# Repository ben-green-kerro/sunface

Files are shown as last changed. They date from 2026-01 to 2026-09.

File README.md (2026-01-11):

# sunface
A big light for your face so you can wake up.

This project aims to provide a bright light to help stimulate wakefullness in the absence of natural light. Our bodies naturally wake when sunlight enters our eyes, even through closed eyelids. Through a WiFi connection, this light may be configured through Apple's HomeKit to smoothly turn on over the course of 30 minutes to reach full brightness at a specific time of desired waking.

White LEDs of a cool 6500k spectrum align with natural sunlight and is also similar in colour spectrum to LEDs used in lamps to treat seasonal affective disorder (SAD). Further to this, the lights brightness is flicker-free due to it the LEDs being powered by constant current driver ICs which is supposed to yield a marked improvement over pulse width modulation for eye-comfort.

A generic wall mount option is available, but the system may also be configured to be attached to a headboard by swapping out the 3D printed mounts at the ends of the light, although this will require some custom design work due to the differences in bed frames.

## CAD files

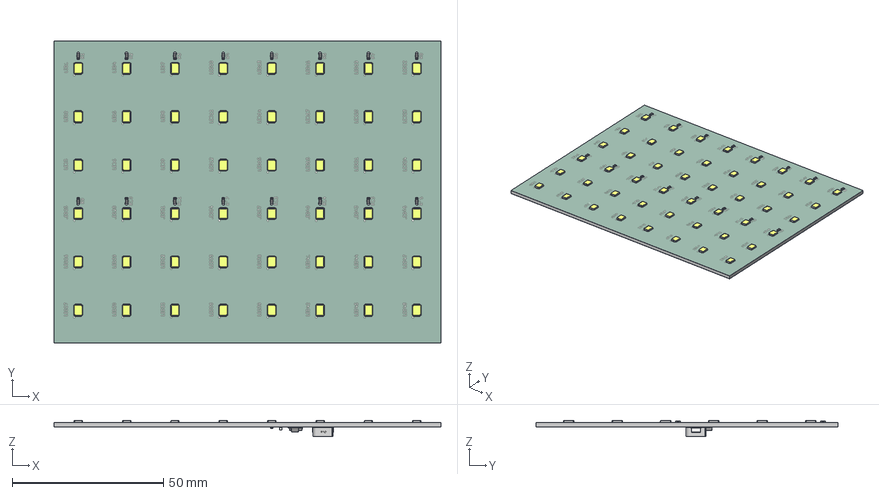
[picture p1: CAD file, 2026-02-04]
hardware/all_in_one/3D Files/sunface.step
128.0 x 100.0 x 5.43 mm
R_0603_1608Metric x 17
LED-SMD_L3.5-W2.8-RD_1.25T-2PWT x 48
C_0603_1608Metric
SOT-89-5_L4.5-W2.5-H1.5-LS4.1-P1.50
IND-SMD_L6.6-W7.1-H3.0
SMA_L4.3-W2.6-LS5.0-RD
sunface_copper
sunface_pad
sunface_via
sunface_silkscreen x 2
sunface_soldermask x 2
sunface_PCB

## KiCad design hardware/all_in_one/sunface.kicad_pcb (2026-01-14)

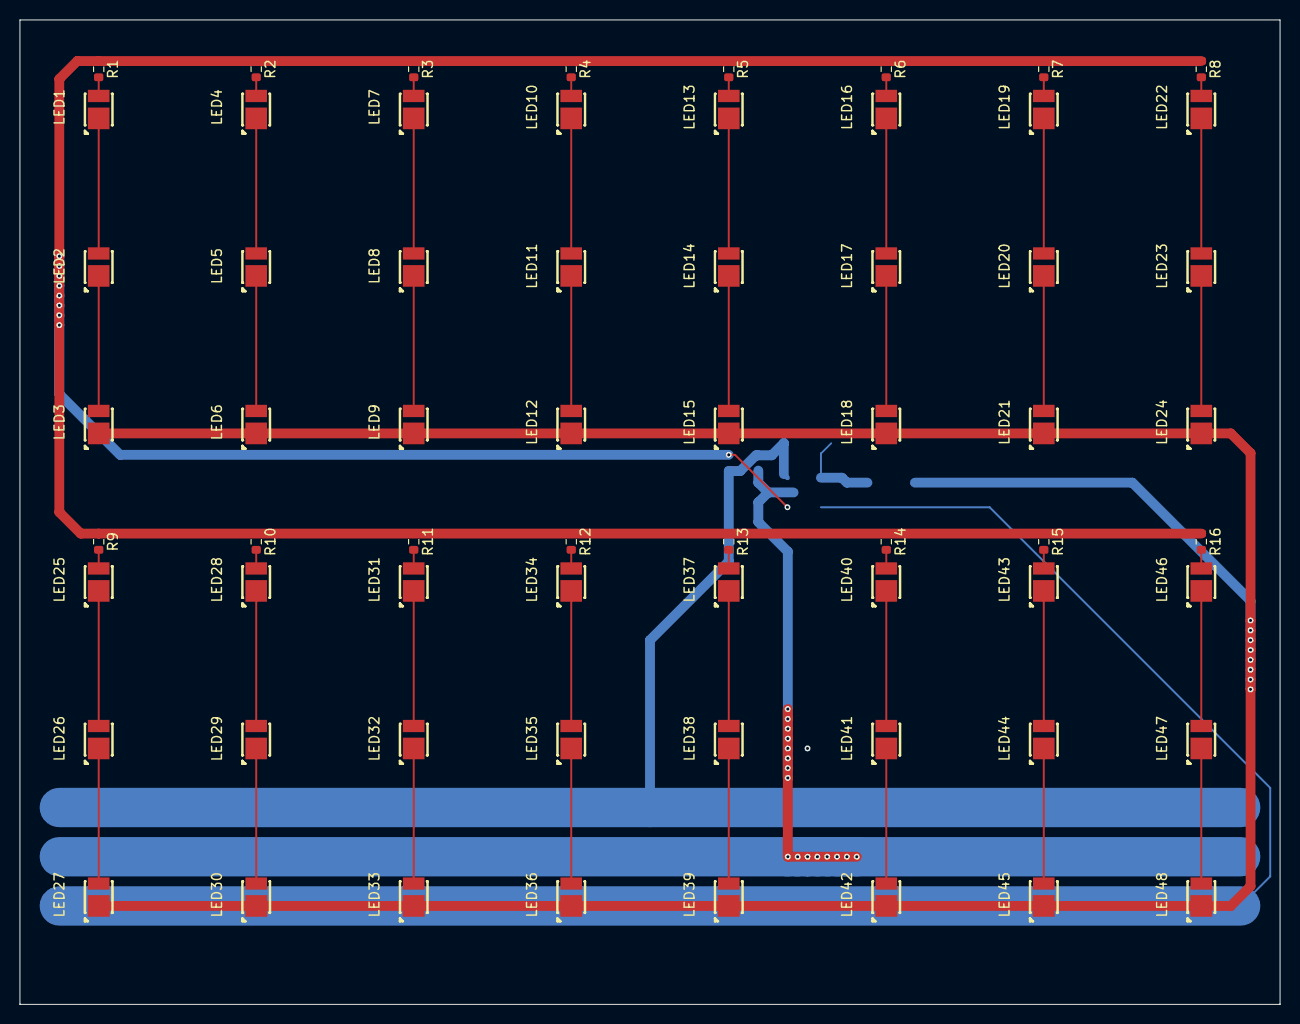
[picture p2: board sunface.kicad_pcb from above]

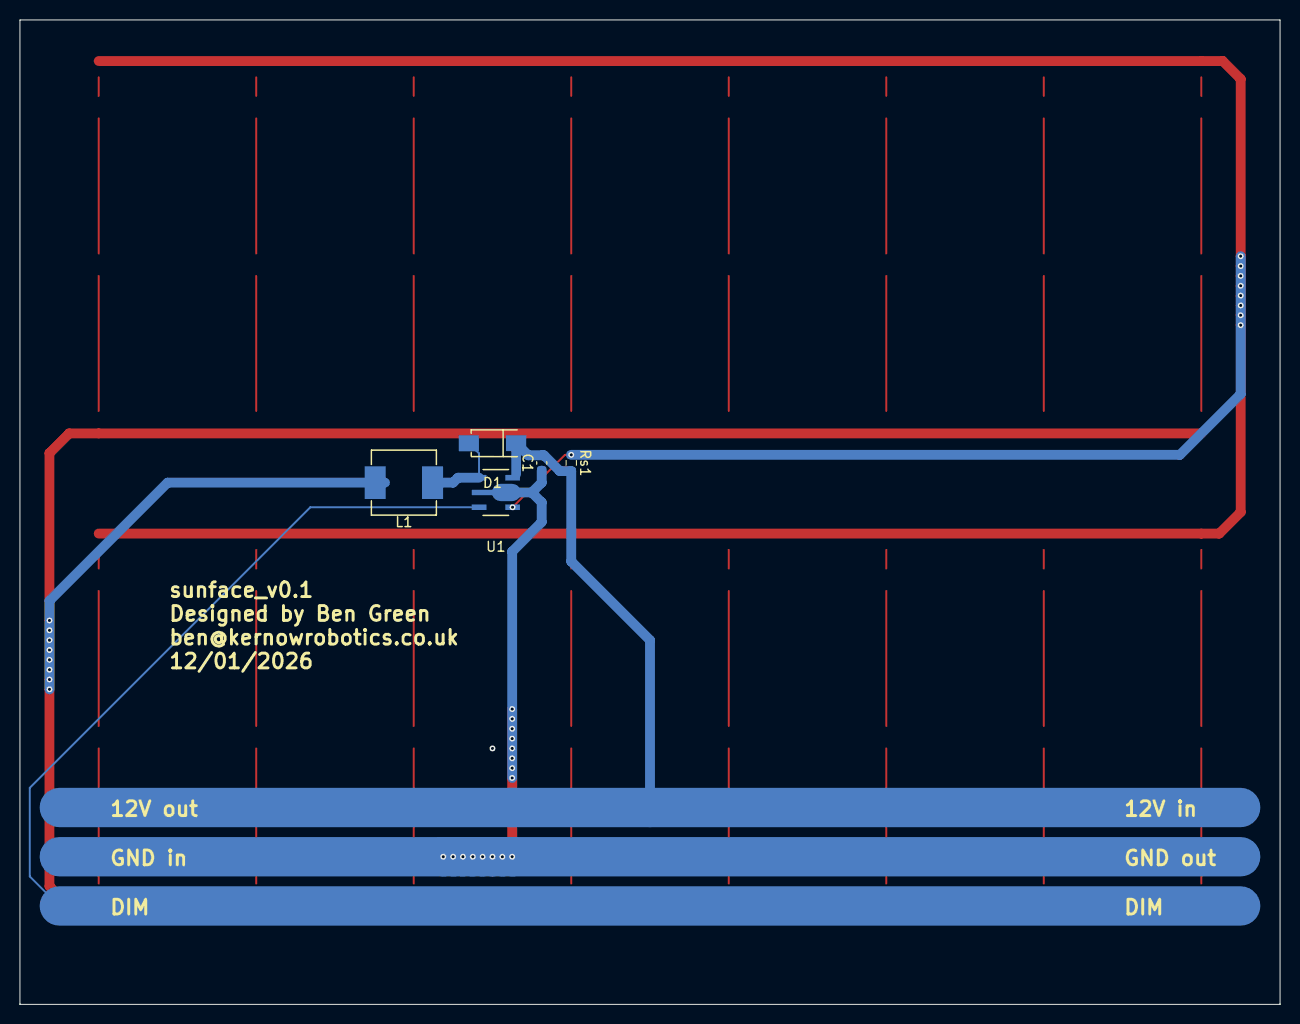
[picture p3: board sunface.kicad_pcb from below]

Board: 2 copper layers, 128.0 x 100.0 mm, 69 parts (5 on the bottom side), 53 nets.

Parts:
C1: 100uF; C_0603_1608Metric
D1: D_Schottky; SMA_L4.3-W2.6-LS5.0-RD
L1: 33uH; IND-SMD_L7.1-W6.6
LED1, LED2, LED3, LED4, LED5, LED6, LED7, LED8, LED9, LED10, LED11, LED12, LED13, LED14, LED15, LED16, LED17, LED18, LED19, LED20, LED21, LED22, LED23, LED24, LED25, LED26, LED27, LED28, LED29, LED30, LED31, LED32, LED33, LED34, LED35, LED36, LED37, LED38, LED39, LED40, LED41, LED42, LED43, LED44, LED45, LED46, LED47, LED48: XL-2835UWC-02; LED-SMD_L3.5-W2.8-RD_1.25T-2PWT
R1, R2, R3, R4, R5, R6, R7, R8, R9, R10, R11, R12, R13, R14, R15, R16: 1R; R_0603_1608Metric
Rs1: 0R1; R_0603_1608Metric
U1: PT4115; SOT-89-5_L4.5-W2.5-P1.50-LS4.5-BR

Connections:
12V: C1.2, D1.1 (K), Rs1.2, U1.5 (VIN)
/led_string1/in: R1.1, R2.1, R3.1, R4.1, R5.1, R6.1, R7.1, R8.1, R9.1, R10.1, R11.1, R12.1, R13.1, R14.1, R15.1, R16.1, Rs1.1, U1.4 (CSN)
/led_string1/out: L1.2, LED3.1 (K), LED6.1 (K), LED9.1 (K), LED12.1 (K), LED15.1 (K), LED18.1 (K), LED21.1 (K), LED24.1 (K), LED27.1 (K), LED30.1 (K), LED33.1 (K), LED36.1 (K), LED39.1 (K), LED42.1 (K), LED45.1 (K), LED48.1 (K)
GND: C1.1, U1.2 (GND)
unnamed: D1.2 (A), L1.1, U1.1 (SW)
unnamed: LED1.2 (A), R1.2
unnamed: LED1.1 (K), LED2.2 (A)
unnamed: LED2.1 (K), LED3.2 (A)
unnamed: LED4.2 (A), R2.2
unnamed: LED4.1 (K), LED5.2 (A)
unnamed: LED5.1 (K), LED6.2 (A)
unnamed: LED7.2 (A), R3.2
unnamed: LED7.1 (K), LED8.2 (A)
unnamed: LED8.1 (K), LED9.2 (A)
unnamed: LED10.2 (A), R4.2
unnamed: LED10.1 (K), LED11.2 (A)
unnamed: LED11.1 (K), LED12.2 (A)
unnamed: LED13.2 (A), R5.2
unnamed: LED13.1 (K), LED14.2 (A)
unnamed: LED14.1 (K), LED15.2 (A)
unnamed: LED16.2 (A), R6.2
unnamed: LED16.1 (K), LED17.2 (A)
unnamed: LED17.1 (K), LED18.2 (A)
unnamed: LED19.2 (A), R7.2
unnamed: LED19.1 (K), LED20.2 (A)
unnamed: LED20.1 (K), LED21.2 (A)
unnamed: LED22.2 (A), R8.2
unnamed: LED22.1 (K), LED23.2 (A)
unnamed: LED23.1 (K), LED24.2 (A)
unnamed: LED25.2 (A), R9.2
unnamed: LED25.1 (K), LED26.2 (A)
unnamed: LED26.1 (K), LED27.2 (A)
unnamed: LED28.2 (A), R10.2
unnamed: LED28.1 (K), LED29.2 (A)
unnamed: LED29.1 (K), LED30.2 (A)
unnamed: LED31.2 (A), R11.2
unnamed: LED31.1 (K), LED32.2 (A)
unnamed: LED32.1 (K), LED33.2 (A)
unnamed: LED34.2 (A), R12.2
unnamed: LED34.1 (K), LED35.2 (A)
unnamed: LED35.1 (K), LED36.2 (A)
unnamed: LED37.2 (A), R13.2
unnamed: LED37.1 (K), LED38.2 (A)
unnamed: LED38.1 (K), LED39.2 (A)
unnamed: LED40.2 (A), R14.2
unnamed: LED40.1 (K), LED41.2 (A)
unnamed: LED41.1 (K), LED42.2 (A)
unnamed: LED43.2 (A), R15.2
unnamed: LED43.1 (K), LED44.2 (A)
unnamed: LED44.1 (K), LED45.2 (A)
unnamed: LED46.2 (A), R16.2
unnamed: LED46.1 (K), LED47.2 (A)
unnamed: LED47.1 (K), LED48.2 (A)

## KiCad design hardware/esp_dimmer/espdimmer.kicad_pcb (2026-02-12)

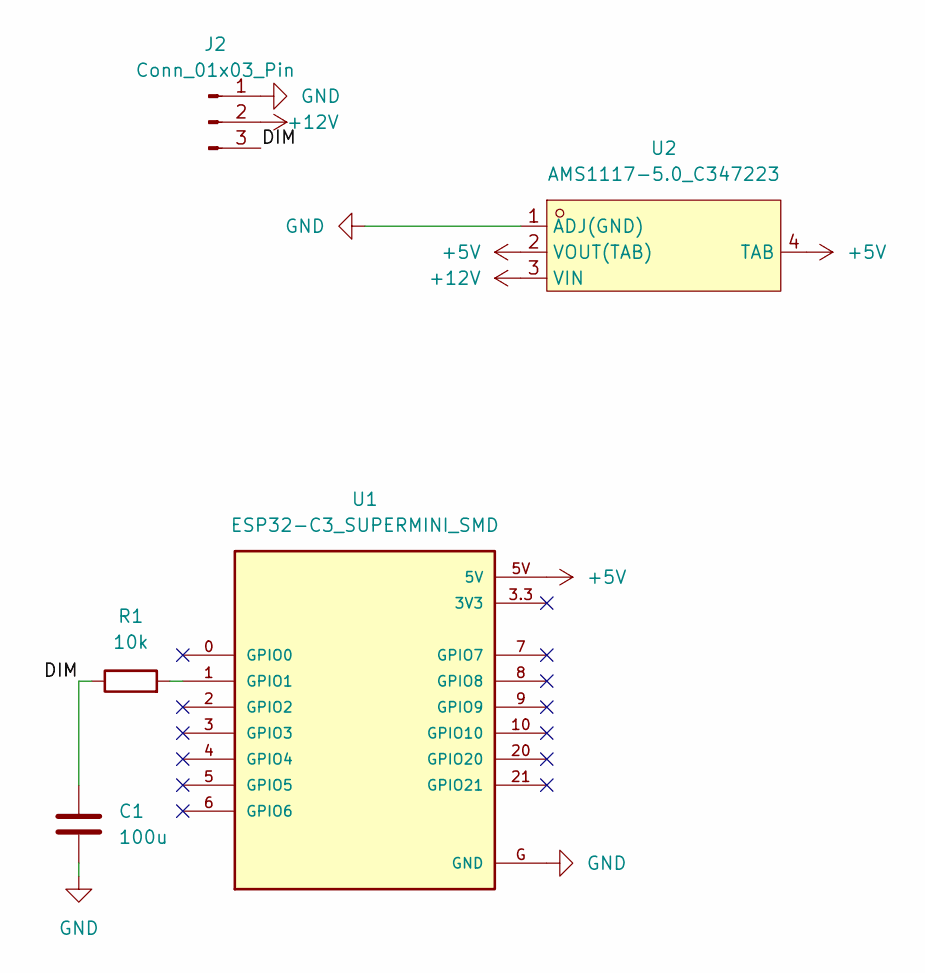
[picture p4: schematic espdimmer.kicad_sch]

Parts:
C1: 100u; C_0603_1608Metric
J2: Conn_01x03_Pin; PinHeader_1x03_P2.54mm_Vertical
R1: 10k; R_0603_1608Metric
U1: ESP32-C3_SUPERMINI_SMD; MODULE_ESP32-C3_SUPERMINI
U2: AMS1117-5.0_C347223; SOT-223_L6.7-W3.5-P2.30-BR; LCSC Part C347223

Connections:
+5V: U1.5V, U2.2 (VOUT(TAB)), U2.4 (TAB)
+12V: J2.2, U2.3 (VIN)
/DIM: C1.1, J2.3, R1.1
GND: C1.2, J2.1, U1.G (GND), U2.1 (ADJ(GND))
unnamed: R1.2, U1.1 (GPIO1)

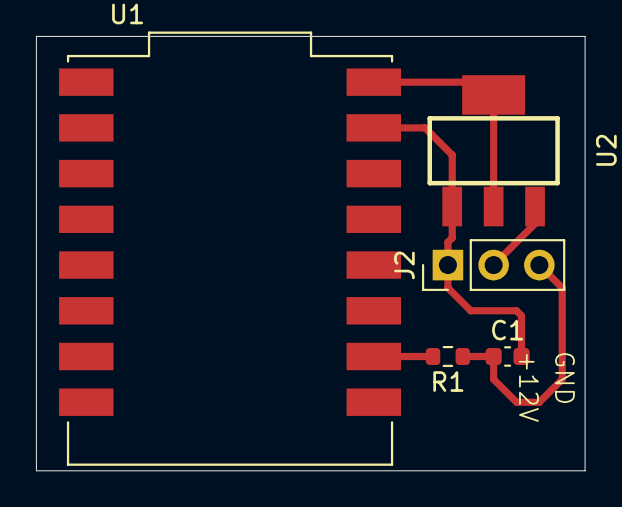
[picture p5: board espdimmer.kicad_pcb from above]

Board: 2 copper layers, 30.5 x 24.1 mm, 5 parts (0 on the bottom side), 5 nets.

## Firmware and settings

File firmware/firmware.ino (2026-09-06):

#include <Arduino.h>


#include <WiFi.h>
#include <time.h>

#include "secrets.h"

const char* ntpServer = "pool.ntp.org";
const long gmtOffset_sec = 0;
const int daylightOffset_sec = 0;

const uint8_t LED_PIN = 4;
const uint32_t PWM_FREQ = 5000;
const uint8_t PWM_RES_BITS = 12;
const uint32_t PWM_MAX_DUTY = pow(2, PWM_RES_BITS) - 1;

int duty = 0;
int oldDuty = 0;

int startTime = (6 * 3600 + 45 * 60);
int peakTime = (7 * 3600 + 15 * 60);
int endTime = (12 * 3600 + 15 * 60);
int offTime = (12 * 3600 + 30 * 60);

void setup() {
  // initialize digital pin LED_BUILTIN as an output.
  pinMode(4, OUTPUT);
  Serial.begin(115200);

  WiFi.mode(WIFI_STA);
  WiFi.begin(ssid, password);

  Serial.print("Connecting to WiFi");
  while (WiFi.status() != WL_CONNECTED) {
    delay(500);
    Serial.print(".");
  }

  Serial.println();
  Serial.print("Connected. IP address: ");
  Serial.println(WiFi.localIP());

  Serial.print("Maximum PWM duty: ");
  Serial.println(PWM_MAX_DUTY);

  configTime(gmtOffset_sec, daylightOffset_sec, ntpServer);

  setenv("TZ", "GMT0BST,M3.5.0/1,M10.5.0/2", 1);
  tzset();

  printLocalTime();
  ledcAttach(LED_PIN, PWM_FREQ, PWM_RES_BITS);
}

void printLocalTime() {
  struct tm timeinfo;
  if (!getLocalTime(&timeinfo)) {
    Serial.println("Failed to obtain time");
    return;
  }
  Serial.println(&timeinfo, "%Y-%m-%d %H:%M:%S");
}

int getSecondsSinceMidnight() {
  struct tm timeinfo;
  getLocalTime(&timeinfo);
  int secondsSinceMidnight = timeinfo.tm_hour * 3600 + timeinfo.tm_min * 60 + timeinfo.tm_sec;
  Serial.print(secondsSinceMidnight);
  Serial.print("    ");
  return secondsSinceMidnight;
}

float getGammaCorrectedBrightness(float normalisedBrightness, float gamma) {
  float gammaCorrectedBrightness = pow(normalisedBrightness, gamma);
  Serial.print(normalisedBrightness, 8);
  Serial.print("    ");

  Serial.print(gammaCorrectedBrightness, 8);
  Serial.print("    ");
  return gammaCorrectedBrightness;
}

int getDuty(float gammaCorrectedBrightness) {
  int duty = gammaCorrectedBrightness * PWM_MAX_DUTY;
  Serial.print(duty);
  Serial.print("    ");
  return duty;
}

int bounce() {
  for (float i = 0.0; i <= 1.0; i = i + 0.01) {
    ledcWrite(4, getDuty(getGammaCorrectedBrightness(i, 2.2)));
    delay(5);
  }
  for (float i = 1.0; i >= 0.0; i = i - 0.01) {
    ledcWrite(4, getDuty(getGammaCorrectedBrightness(i, 2.2)));
    delay(5);
  }
}

int pulse() {
  int t = millis();
  float phase = (2.0f * 3.14159 * (t % (unsigned long)2000.0)) / 2000.0;
  Serial.print(phase);
  Serial.print("    ");
  float brightness = 0.5f * (sinf(phase) + 1.0f);
  ledcWrite(4, getDuty(getGammaCorrectedBrightness(brightness / 2, 2.2)));
  Serial.print(brightness);
  Serial.print("    ");
  Serial.println();
}

void daily() {
  int secondsSinceMidnight = getSecondsSinceMidnight();
  float normalisedBrightness = 0.0;
  if (secondsSinceMidnight < startTime) {
    Serial.print("Phase 1    ");
    normalisedBrightness = 0.0;
  } else if (secondsSinceMidnight < peakTime) {
    Serial.print("Phase 2    ");
    int fadeTime = peakTime - startTime;
    int secondsSinceStart = secondsSinceMidnight - startTime;
    Serial.print(secondsSinceStart);
    Serial.print("    ");
    normalisedBrightness = secondsSinceStart / float(fadeTime);
  } else if (secondsSinceMidnight < endTime) {
    Serial.print("Phase 3    ");
    normalisedBrightness = 1.0;
  } else if (secondsSinceMidnight < offTime) {
    Serial.print("Phase 4    ");
    int fadeTime = offTime - endTime;
    int secondsSinceEnd = secondsSinceMidnight - endTime;
    normalisedBrightness = 1.0 - (secondsSinceEnd / float(fadeTime));
  } else {
    Serial.print("Phase 5    ");
    normalisedBrightness = 0.0;
  }

  float gammaCorrectedBrightness = getGammaCorrectedBrightness(normalisedBrightness, 2.2);
  int duty = getDuty(gammaCorrectedBrightness);
  ledcFade(4, oldDuty, duty, 1000);
  oldDuty = duty;
  delay(1000);  // wait for a second
  Serial.println();
}

void loop() {
  daily();
  // bounce();
  // pulse();
}

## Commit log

2026-01-10 create kicad project
    [Untitled.kicad_pcb, Untitled.kicad_sch]
2026-01-10 Revert "create kicad project"
    This reverts commit 13162ccaef517c462fcfb8ae84759984098fcdda.
    [Untitled.kicad_pcb, Untitled.kicad_sch]
2026-01-10 add initial project files
    [sunface.kicad_pcb, sunface.kicad_sch]
2026-01-10 Revert "add initial project files"
    This reverts commit d966b0f5216c83924483581c6c6f5e4b1e73409e.
    [sunface.kicad_pcb, sunface.kicad_sch]
2026-01-10 add initial files
    [sunface.kicad_pcb, sunface.kicad_sch]
2026-01-10 set design rules
    [sunface.kicad_pcb]
2026-01-11 add led driver datasheet
2026-01-11 add led datasheet
2026-01-11 add led string schematic
    [led_string.kicad_sch]
2026-01-11 add initial schematic details from datasheet
    [sunface.kicad_sch]
2026-01-11 add schottky footprint
    [sunface.kicad_sch]
2026-01-11 arrange all components
    [led_string.kicad_sch, sunface.kicad_pcb, sunface.kicad_sch]
2026-01-14 finalise design for manufacture
    [sunface.kicad_pcb, sunface.kicad_sch]
2026-01-14 fix 3d files
    [sunface.kicad_pcb]
2026-02-04 Change folder structure
    [led_string.kicad_sch, sunface.kicad_pcb, sunface.kicad_sch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]
2026-02-12 Add esp dimmer to project
    [espdimmer.kicad_pcb, espdimmer.kicad_sch, led_string.kicad_sch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]
2026-09-06 Move Wi-Fi credentials to secrets.h and ignore it
    Remove hard-coded Wi‑Fi SSID/password from firmware/firmware.ino and replace with #include "secrets.h". Add firmware/secrets.h.example with placeholder values and update .gitignore to ignore firmware/secrets.h (plus a brief comment). This keeps real credentials out of the repo; copy secrets.h.example to firmware/secrets.h and fill in your values.
    [firmware.ino]
